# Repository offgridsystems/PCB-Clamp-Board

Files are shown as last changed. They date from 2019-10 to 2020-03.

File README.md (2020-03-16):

# Clamp Board PCBs
### Hardware Files For both Dkblock Clamp Boards - 7.4V and 3.7V (one of each needed for each DKblock)
These are the printed circuit board (PCB) files, CAD files, specification sheets and all technical drawings needed to make each DKblock Clamp board. Note that the bill of materials (BOM) and other technical documents can be opened in [OpenOffice](https://www.openoffice.org) format and PCB files are in [EAGLE](https://www.autodesk.com/products/eagle/overview) format, but they can also be opened and edited in the open source Kicad program.
One version is provided for each board, Rev C are fully tested boards, put into limited production and used on a 72VDC electric scooter named Fido, and a 150VDC VW bug conversion, and other EV projects. 
Also note that the cells have 20 amp fuse protection on each cell. See "Blowup of trace fuse with comments.pdf" graphic

Clamp Board 7.4v 0v OutSide

Clamp Board 7.4v 0v Inside

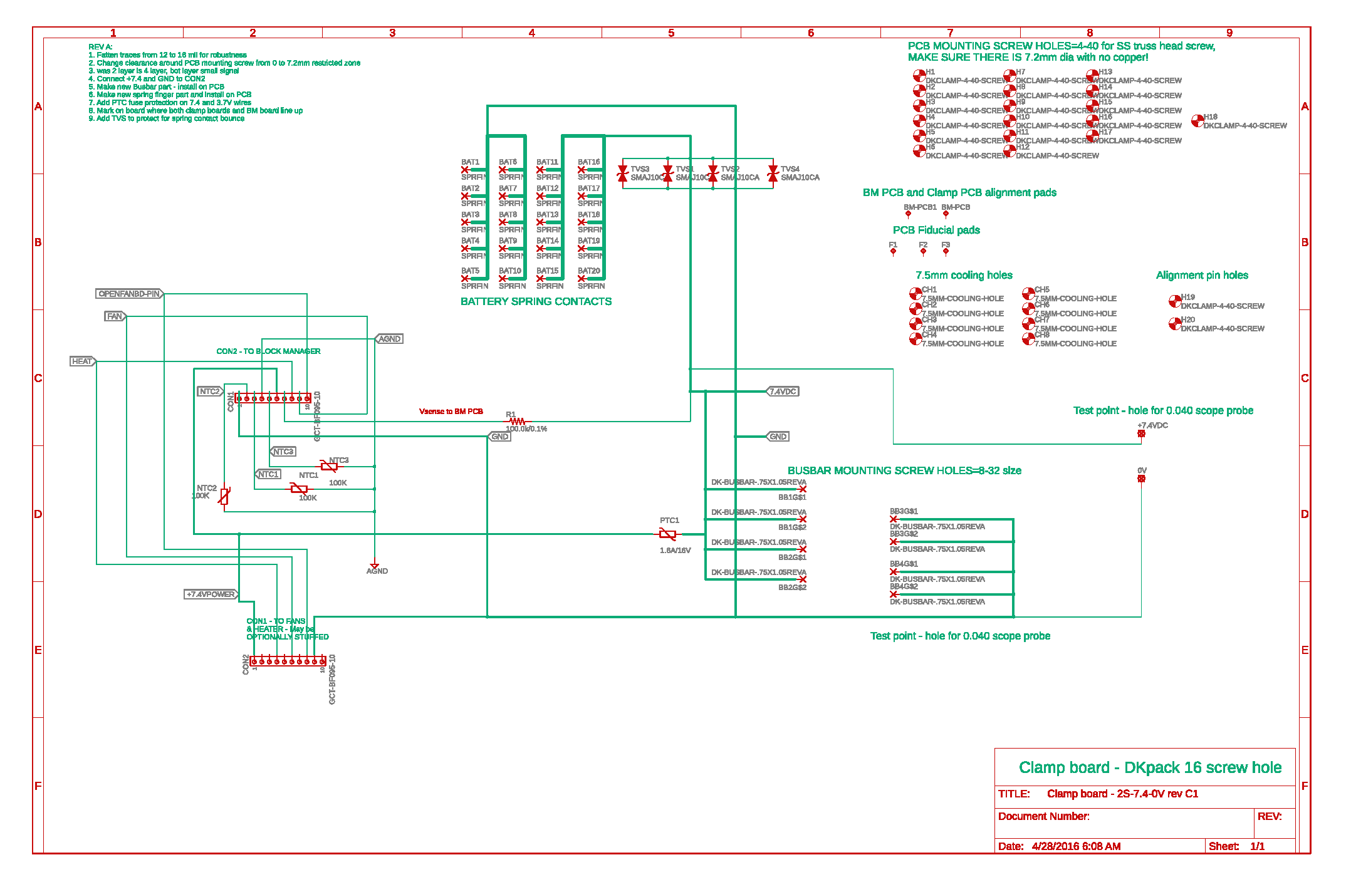
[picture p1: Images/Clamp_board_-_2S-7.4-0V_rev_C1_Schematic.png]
Clamp Board 7.4v 0v Schematic


Clamp Board 3.7v OutSide

Clamp Board 3.7v Inside

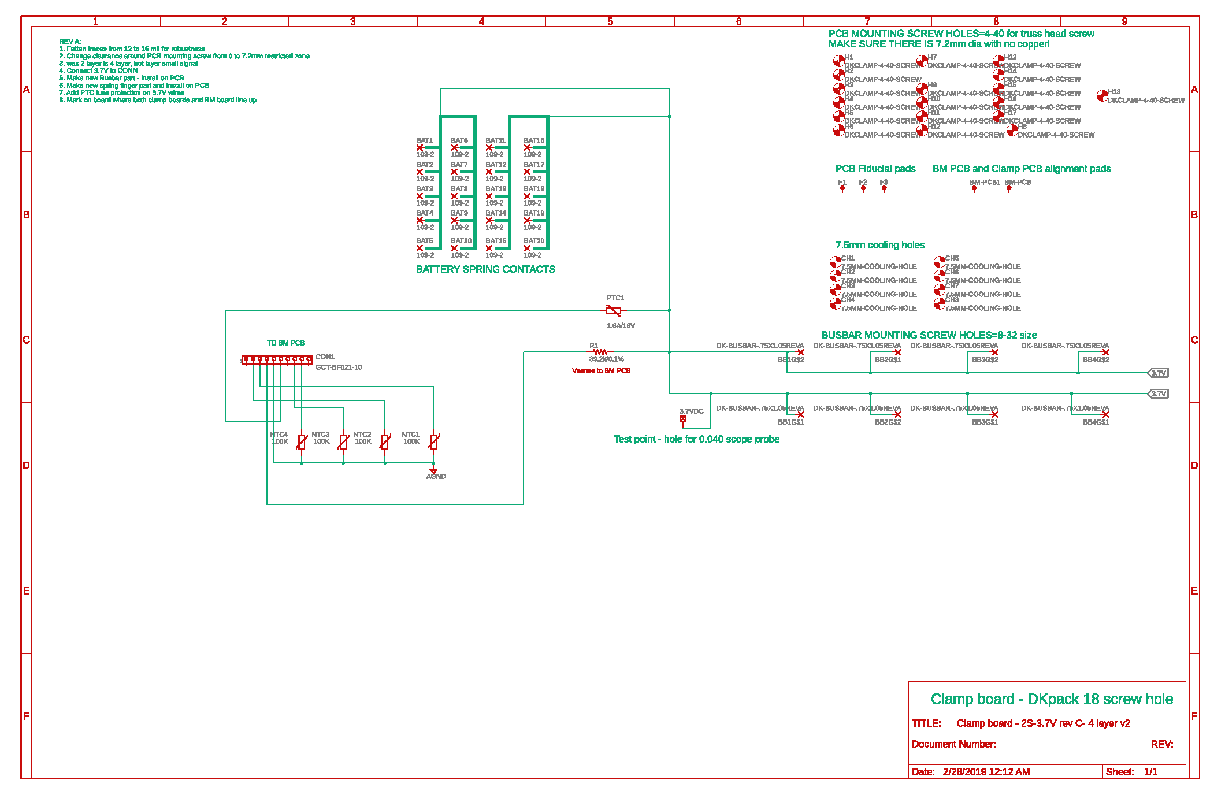
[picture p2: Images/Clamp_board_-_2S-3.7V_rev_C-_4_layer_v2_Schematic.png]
Clamp Board 3.7v Schematic


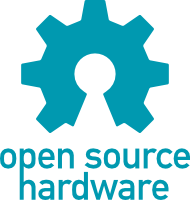
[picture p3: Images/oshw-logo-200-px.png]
Open Hardware


All DKblock software and hardware is released as open source hardware (OSHW) as defined by the OSHWA: https://www.oshwa.org/definition/ and under the JSON license defined at https://www.json.org/license.html

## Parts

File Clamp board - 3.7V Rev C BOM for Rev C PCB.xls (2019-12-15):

BOM – Clamp board 3.7V Rev C For Rev C Boards
Qty | Value | Device | Package | Parts | Description | 1KPRICE | 100PCPRICE | ext 1k | Ext 100 | MPN
1 | 39.2k/0.1% | Resistor SMT | R0603 | R1 | Resistor, SMT | 0.079 | 0.16 | 0.079 |  | Susumu RG1608P-3922-B-T5
4 | 100K | NTC thermistor | R0603 | NTC1, NTC2, NTC3, NTC4 | THERMISTOR NTC 100K OHM 5% 0603 | 0.008 | 0.106 | 0.032 | 0.424 | Murata NCP18WF104J03RB
20 | Gold spring finger | DK springfinger Rev B |  | BAT1-BAT20 | BATTERY CONTACT UNIVERSAL PCB | 0.1 | 0.1 | 2 | 2 | DK spring finger Rev A-1
1 | PCB, FR4 Tg180, 4 layer |  |  | PCB | PCB, 4 layer, 1 ounce copper, TG180 Rev B | 3.43 | 7.7 | 3.43 | 7.7 | Best Tech
1 | 1.6A PTC | PTC fuse | SMT | PTC1 | PTC RESTTBLE 1.60A 16V CHIP 1812 | 0.094 | 0.13 | 0.094 | 0.13 | Bel 0ZCG0160BF2C
1 | 10 pin header | Male single inline pin header | 1 row x 10 positions | CON1 | 2mm single row pin header 10 pin thru hole R/A | 0.6 | 1 | 0.6 | 1 | GCT BF021-10-A-B-0400-0250-N | Sullins NRPN401PARN-RC (40 pin SIP will have to break into 4 pcs of 10 pin connector)
 |  |  |  |  | total |  |  | 6.235 | 11.254

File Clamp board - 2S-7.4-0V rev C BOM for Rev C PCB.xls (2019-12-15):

BOM – Clamp board – 7.4V Rev C BOM for Rev C PCB
Qty | QOH | Ordered | Value | Device | Package | Parts | Description | 1KPRICE | 100PCPRICE | ext 1k | Ext 100 | MPN |  | alternative PN
3 |  | x | 100K/2% | Thermistor NTC | R0603 | NTC1, NTC2, NTC3 | Murata NCP18WF104J03RB | 0.008 | 0.106 | 0.024 | 0.318 | Murata NCP18WF104J03RB
20 |  | x | Gold spring finger | DK springfinger Rev B |  | BAT1, BAT2, BAT3, BAT4, BAT5, BAT6, BAT7, BAT8, BAT9, BAT10, BAT11, BAT12, BAT13, BAT14, BAT15, BAT16, BAT17, BAT18, BAT19, BAT20 | BATTERY CONTACT UNIVERSAL PCB | 0.1 | 0.1 | 2 | 2 | DK spring finger Rev A-1
1 | 50 |  | Female inline socket | 2mm SMT socket, dual entry | TH single row 10 pos | CON1 | 2.0 mm socket, 10 pos, single row, gold, phosphor bronze | 0.27 | 1 | 0.27 | 1 | GCT BF085-10-A-0240-N-D | 3k min | Sullins NPPN101BFCN-RC
1 |  |  | PCB, FR4 Tg180, 4 layer |  |  | PCB | PCB, 4 layer, 1 ounce copper, TG180, Rev B | 3.43 | 7.7 | 3.43 | 7.7 | Best Tech
1 | x |  | 1.6A PTC | PTC fuse | SMT | PTC1 | PTC RESTTBLE 1.60A 16V CHIP 1812 | 0.094 | 0.13 | 0.094 | 0.13 | Bel 0ZCG0160BF2C
4 |  | x | TVS | SMAJ10CA |  | TVS1, TVS2, TVS3, TVS4 | TVS DIODE, Bidirectional 10VWM 21.7VC SMA | 0.08 | 0.105 | 0.32 | 0.42 | ST SMAJ10CA-TR
1 |  | x | 100k/0.1% | Precision resistor | R0603 | R1 | RES SMD 100K OHM 0.1% 1/10W 0603 | 0.079 | 0.16 | 0.079 | 0.16 | Susumu RG1608P-104-B-T5 |  | Yageo RT0603BRD07100KL
 |  |  |  |  |  |  | total |  |  | 6.217 | 11.728
 | DO NOT STUFF THESE PARTS!!! |  |  |  |  | DO NOT STUFF THESE PARTS!!! |  |  |  | 0
1 | 50 |  | Female inline socket | 2mm SMT socket, dual entry | TH single row 10 pos | CON2 | 2.0 mm socket, 10 pos, single row, gold, phosphor bronze | 0.27 | 1 | 0.27 | 1 | GCT BF085-10-A-0240-N-D | 3k min | Sullins NPPN101BFCN-RC

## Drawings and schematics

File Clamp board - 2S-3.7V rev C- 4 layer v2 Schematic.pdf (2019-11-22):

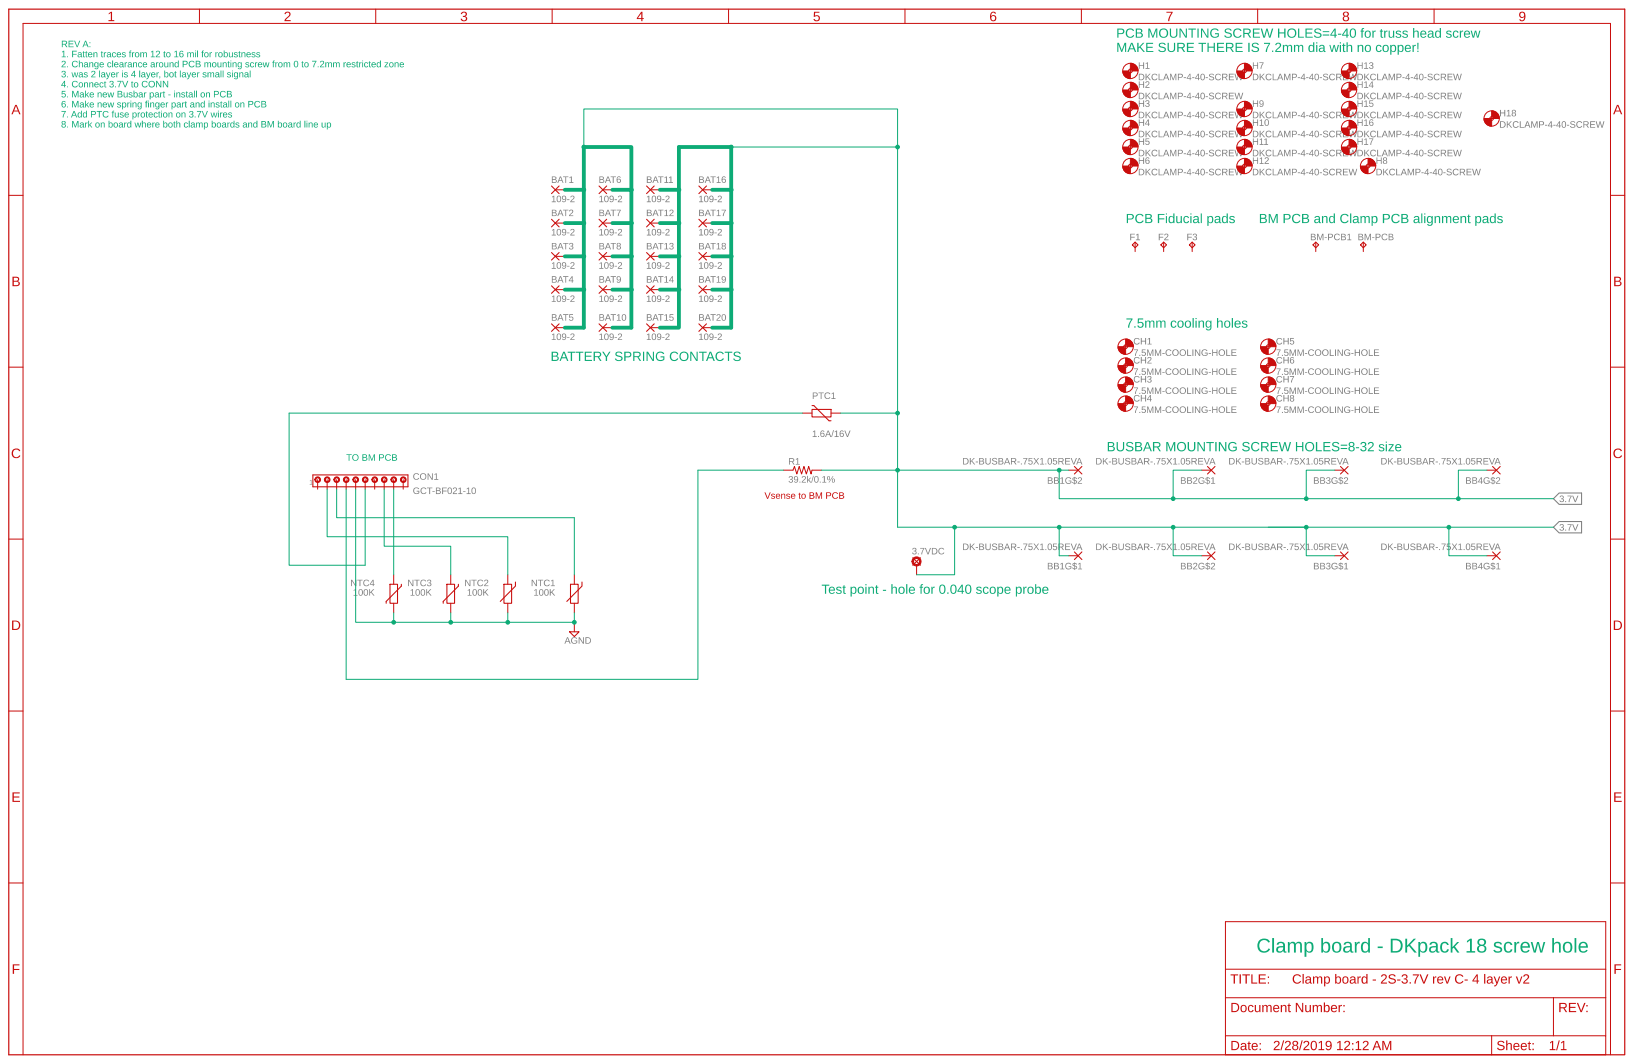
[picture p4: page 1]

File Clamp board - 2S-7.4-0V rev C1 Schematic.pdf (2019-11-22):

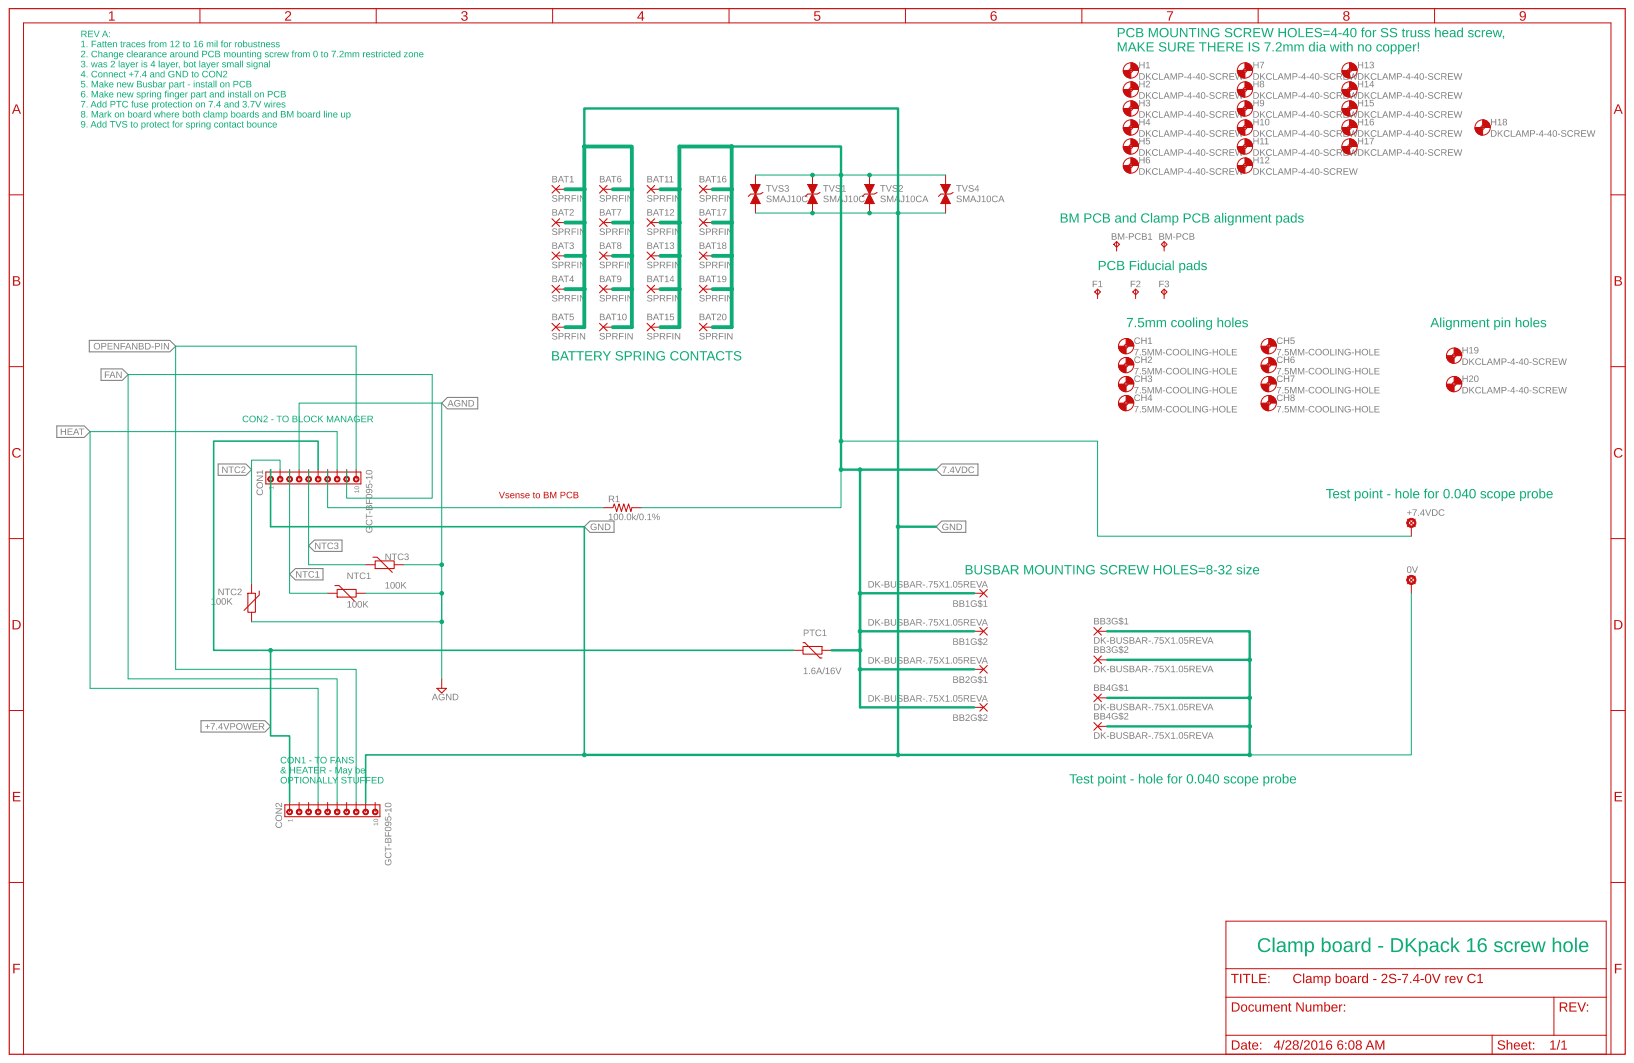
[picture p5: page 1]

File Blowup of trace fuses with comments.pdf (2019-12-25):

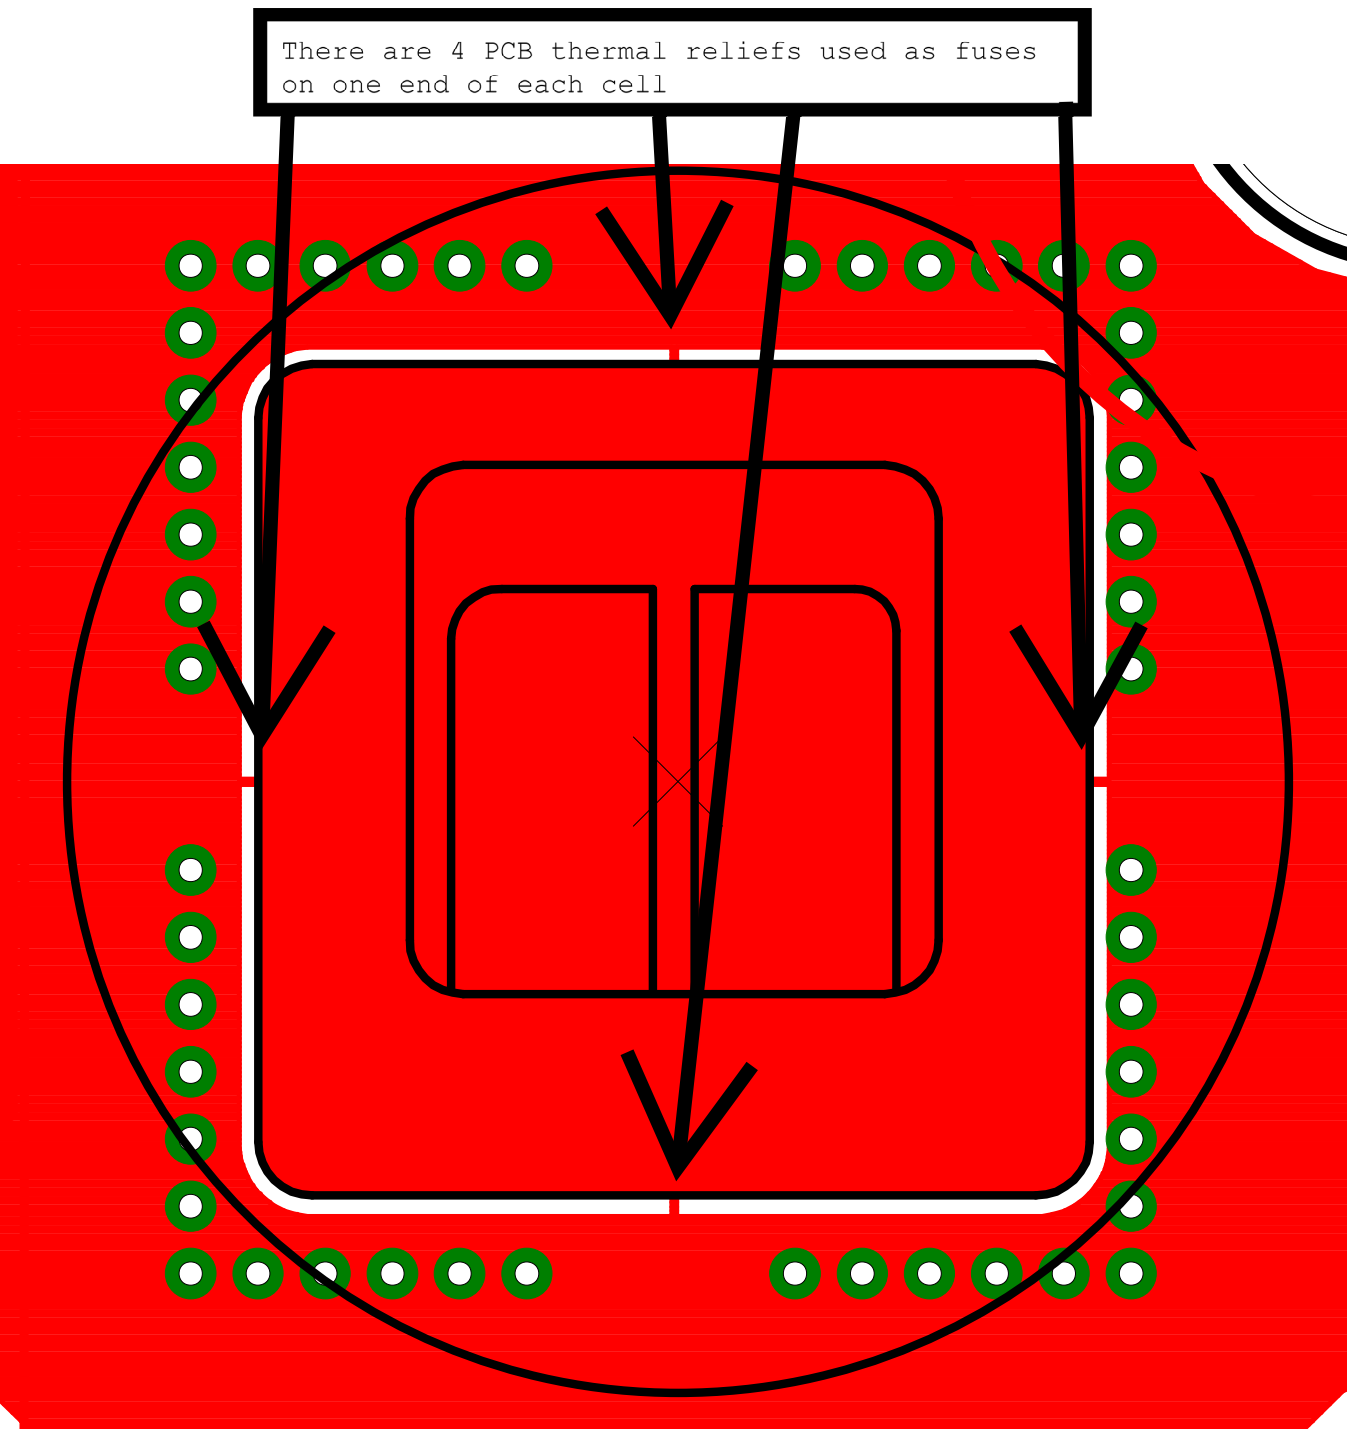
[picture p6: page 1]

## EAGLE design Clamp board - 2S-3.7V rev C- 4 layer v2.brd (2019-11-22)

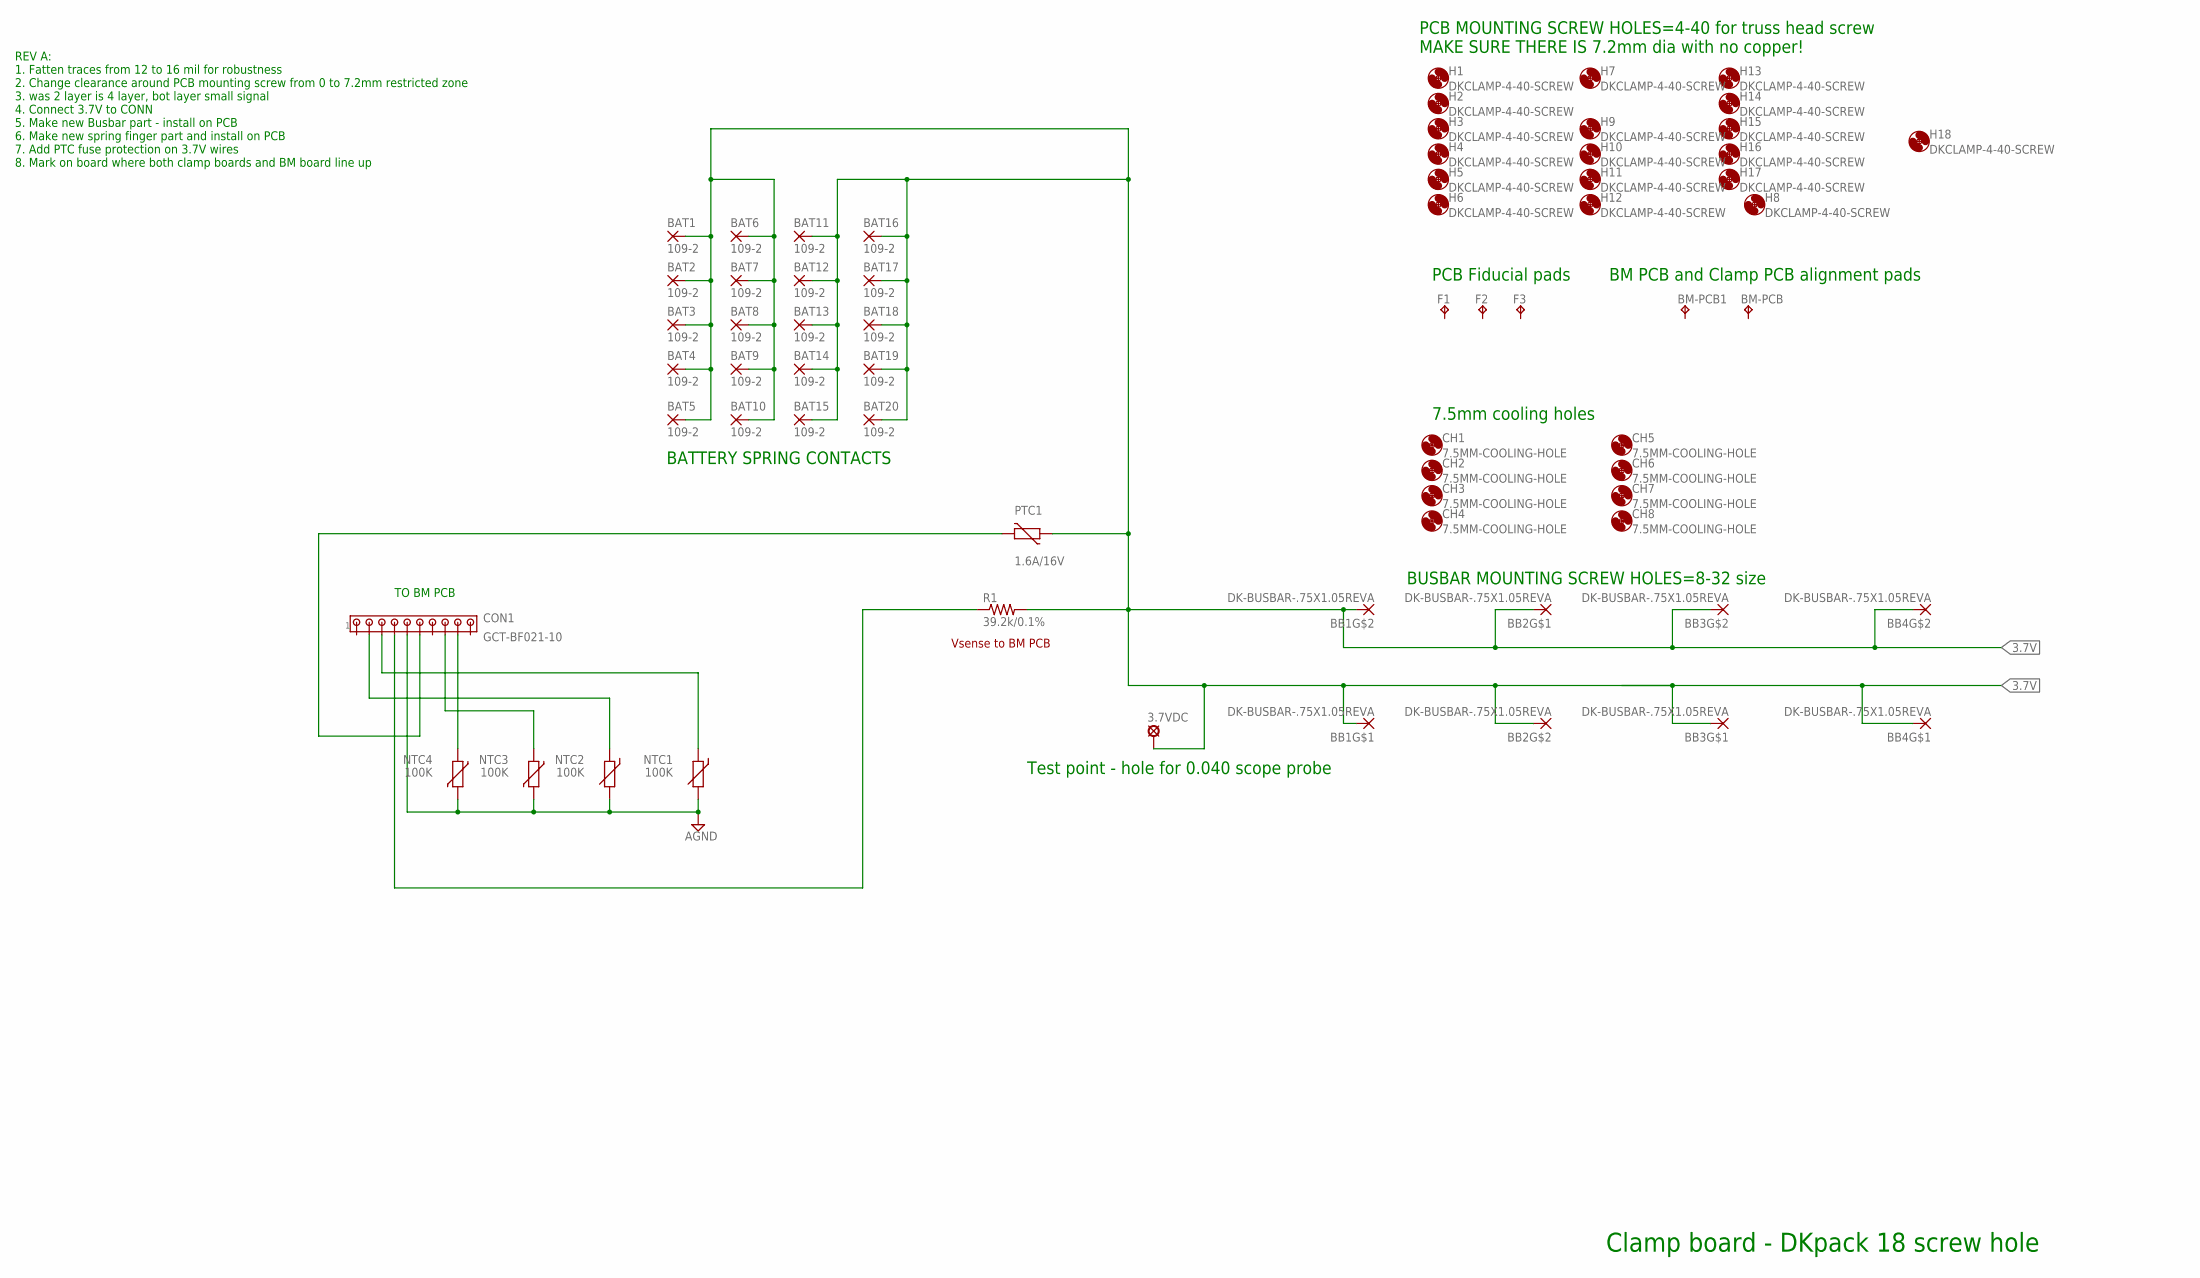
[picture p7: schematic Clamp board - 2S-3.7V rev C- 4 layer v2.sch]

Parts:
3.7VDC: LSP10
BAT1, BAT2, BAT3, BAT4, BAT5, BAT6, BAT7, BAT8, BAT9, BAT10, BAT11, BAT12, BAT13, BAT14, BAT15, BAT16, BAT17, BAT18, BAT19, BAT20: 109-2; DK-SPRING-FINGER-REV2
BB1, BB2, BB3, BB4: DK-BUSBAR-.75X1.05REVA; DKBUSBAR
BM-PCB, BM-PCB1: FIDUCIALTP15SQ; TP15SQ
CH1, CH2, CH3, CH4, CH5, CH6, CH7, CH8: 7.5MM-COOLING-HOLE
CON1: GCT-BF021-10
F1, F2, F3: FIDUCIALB1,27; B1,27
H1, H2, H3, H4, H5, H6, H7, H8, H9, H10, H11, H12, H13, H14, H15, H16, H17, H18: DKCLAMP-4-40-SCREW; 2.95MM-HOLE-FOR-4-40SCREW-DKCLAMP
NTC1, NTC2: 100K; 0603
NTC3, NTC4: 100K; VARISTOR_0603
PTC1: 1.6A/16V; CT/CN1812; MPN Bel 0ZCG0160BF2C
R1: 39.2k/0.1%; R0603

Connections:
3.7V: 3.7VDC.MP, BAT1.2, BAT2.2, BAT3.2, BAT4.2, BAT5.2, BAT6.2, BAT7.2, BAT8.2, BAT9.2, BAT10.2, BAT11.2, BAT12.2, BAT13.2, BAT14.2, BAT15.2, BAT16.2, BAT17.2, BAT18.2, BAT19.2, BAT20.2, BB1.P$2, BB1.P$3, BB2.P$2, BB2.P$3, BB3.P$2, BB3.P$3, BB4.P$2, BB4.P$3, PTC1.1, R1.2
3.7VPOWER: CON1.P$6 (6), PTC1.2
3.7VSCALED: CON1.P$4 (4), R1.1
AGND: CON1.P$5 (5), NTC1.2, NTC2.2, NTC3.2, NTC4.2
NTC1: CON1.P$3 (3), NTC1.1
NTC2: CON1.P$2 (2), NTC2.1
NTC3: CON1.P$8 (8), NTC3.1
NTC4: CON1.P$9 (9), NTC4.1

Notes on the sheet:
Clamp board - DKpack 18 screw hole
PCB MOUNTING SCREW HOLES=4-40 for truss head screw MAKE SURE THERE IS 7.2mm dia with no copper!
BATTERY SPRING CONTACTS
PCB Fiducial pads
7.5mm cooling holes
Test point - hole for 0.040 scope probe
TO BM PCB
BUSBAR MOUNTING SCREW HOLES=8-32 size
Vsense to BM PCB
REV A: 1. Fatten traces from 12 to 16 mil for robustness 2. Change clearance around PCB mounting screw from 0 to 7.2mm restricted zone 3. was 2 layer is 4 layer, bot layer small signal 4. Connect 3.7V to CONN 5. Make new Busbar part - install on PCB 6. Make new spring finger part and install on PCB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
BM PCB and Clamp PCB alignment pads

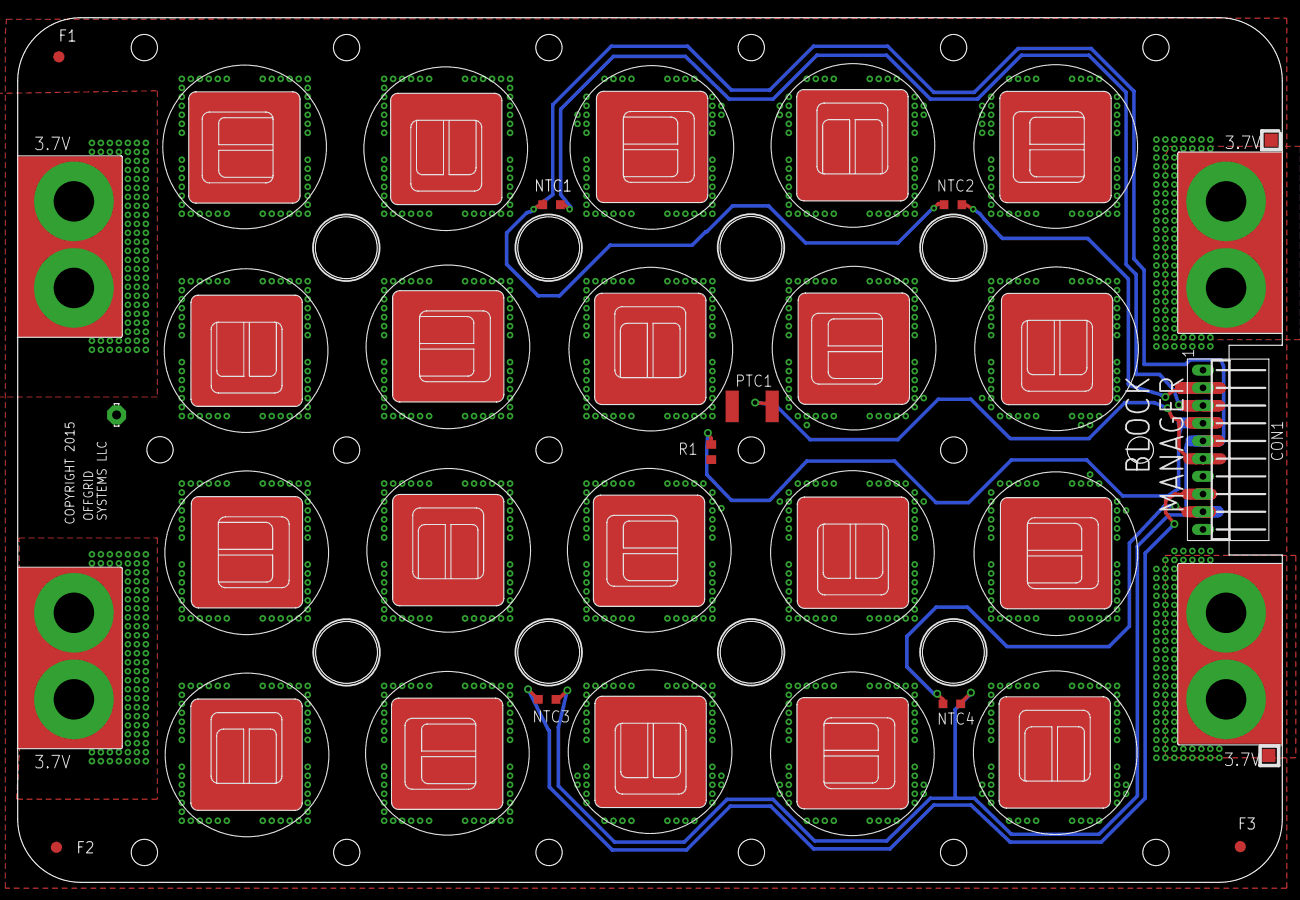
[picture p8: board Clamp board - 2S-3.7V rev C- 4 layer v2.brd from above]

Board: 4 copper layers, 142.9 x 97.7 mm, 63 parts (0 on the bottom side), 8 nets.

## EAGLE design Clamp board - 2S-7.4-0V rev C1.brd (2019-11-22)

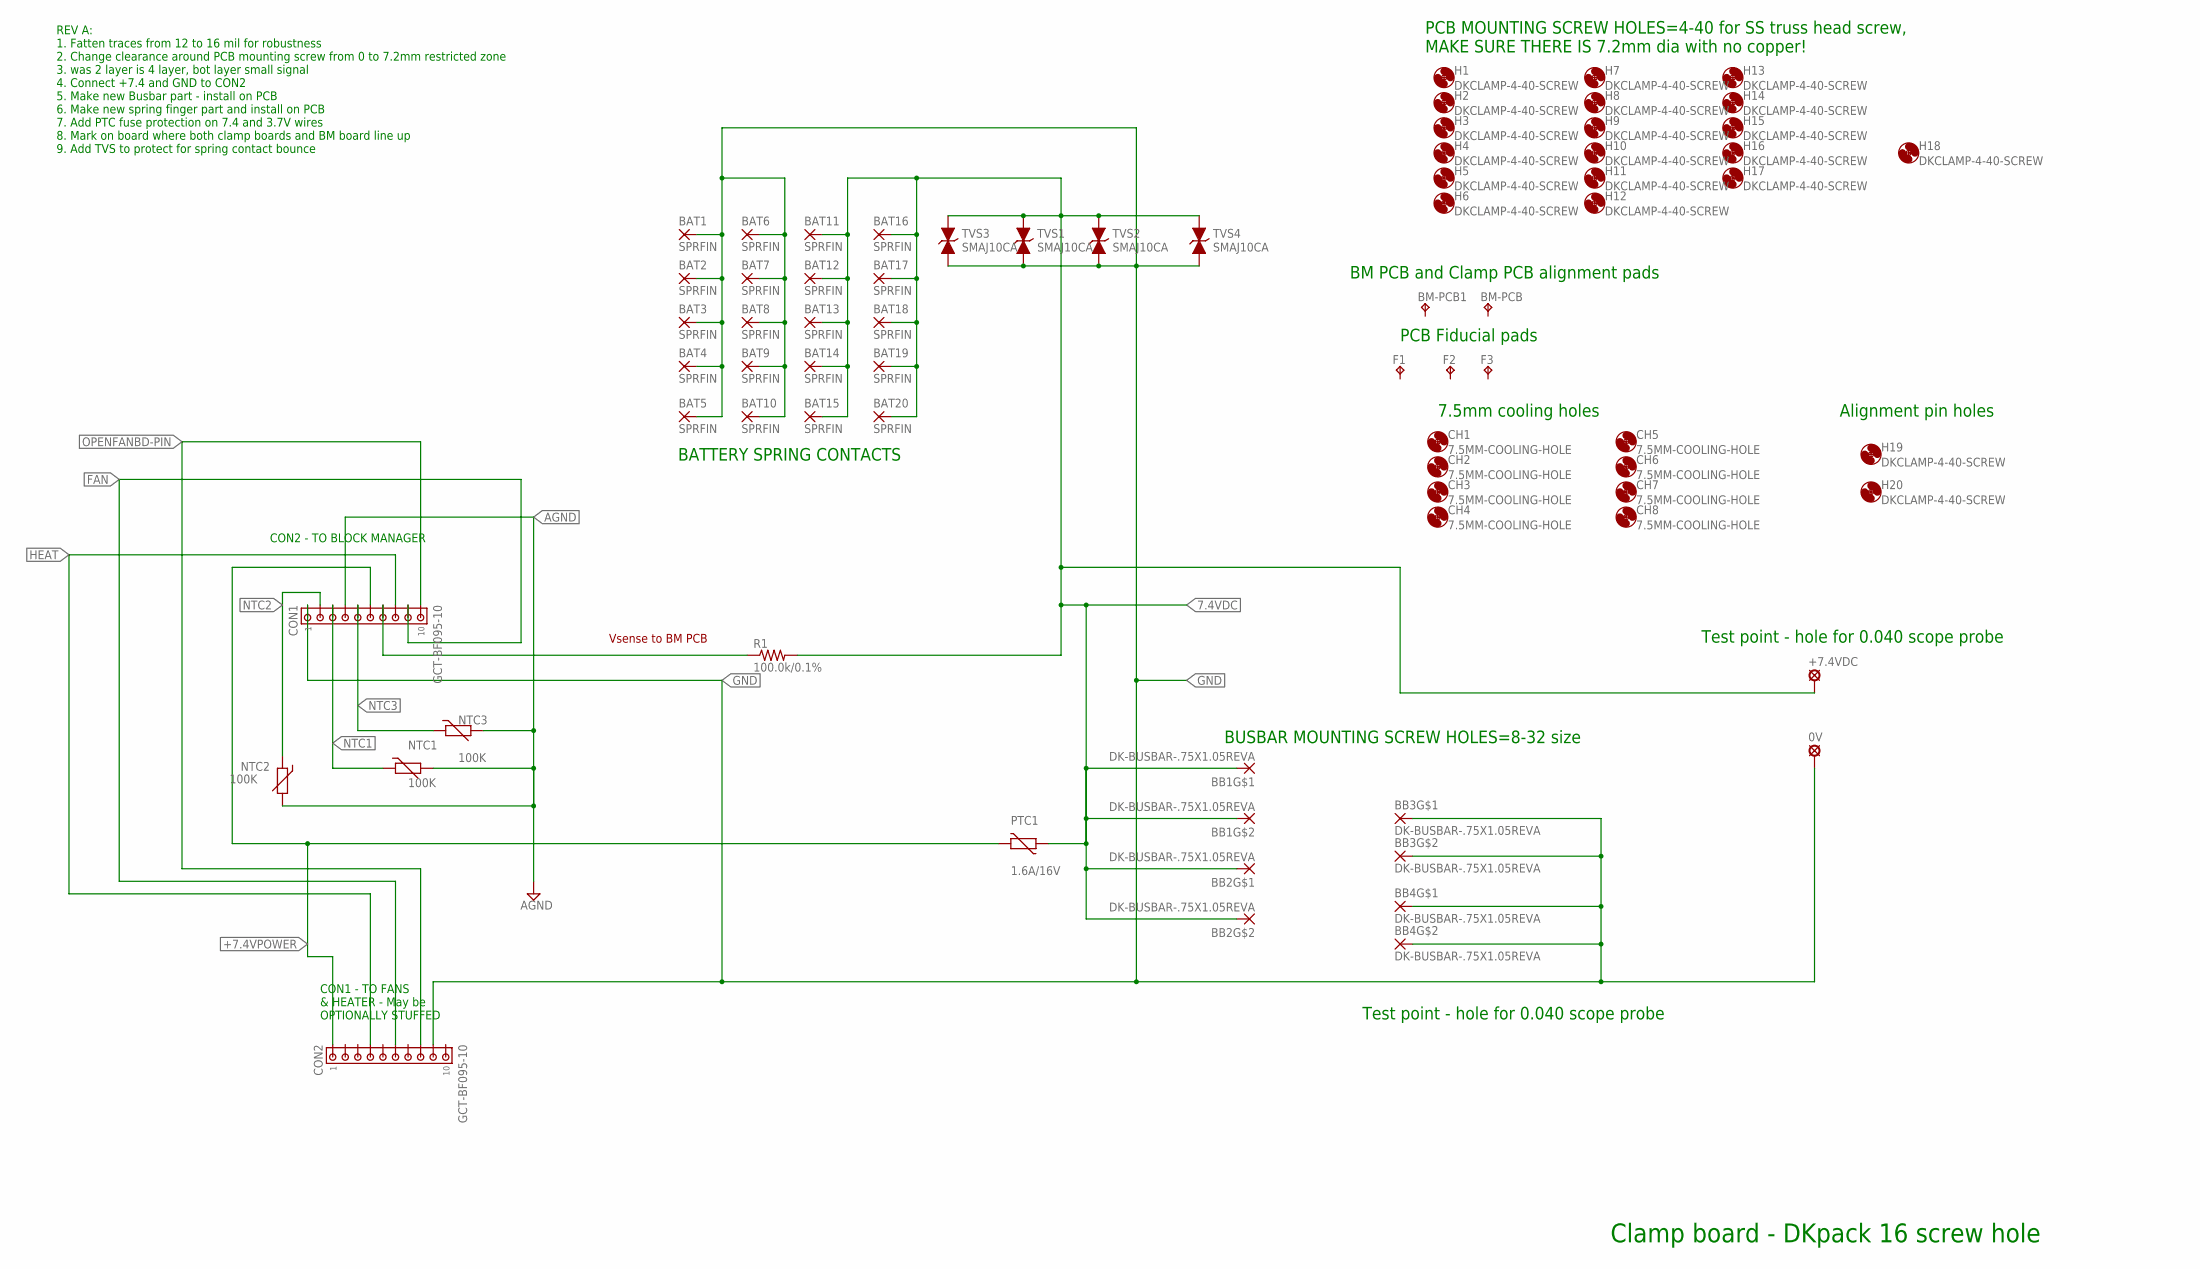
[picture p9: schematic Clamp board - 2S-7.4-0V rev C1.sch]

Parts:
0V: LSP10
+7.4VDC: LSP10
BAT1: SPRFIN; DK-SPRING-FINGER-REV2; MPN Keystone 109-2
BAT2, BAT3, BAT4, BAT5, BAT6, BAT7, BAT8, BAT9, BAT10, BAT11, BAT12, BAT13, BAT14, BAT15, BAT16, BAT17, BAT18, BAT19, BAT20: SPRFIN; DK-SPRING-FINGER-REV2
BB1, BB2, BB3, BB4: DK-BUSBAR-.75X1.05REVA; DKBUSBAR
BM-PCB, BM-PCB1: FIDUCIALTP15SQ; TP15SQ
CH1, CH2, CH3, CH4, CH5, CH6, CH7, CH8: 7.5MM-COOLING-HOLE
CON1, CON2: GCT-BF095-10; GCT-BF085-10
F1, F2, F3: FIDUCIALB1,27; B1,27
H1, H2, H3, H4, H5, H6, H7, H8, H9, H10, H11, H12, H13, H14, H15, H16, H17, H18, H19, H20: DKCLAMP-4-40-SCREW; 2.95MM-HOLE-FOR-4-40SCREW-DKCLAMP
NTC1, NTC2, NTC3: 100K; 0603; MPN MURATA NCP18WF104J03RB
PTC1: 1.6A/16V; CT/CN1812; MPN Bel 0ZCG0160BF2C
R1: 100.0k/0.1%; R0603
TVS1, TVS2, TVS3, TVS4: SMAJ10CA; SMAJ; MPN ST SMAJ10CA-TR

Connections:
7.4VDC: +7.4VDC.MP, BAT11.2, BAT12.2, BAT13.2, BAT14.2, BAT15.2, BAT16.2, BAT17.2, BAT18.2, BAT19.2, BAT20.2, BB1.P$2, BB1.P$3, BB2.P$2, BB2.P$3, PTC1.1, R1.2, TVS1.K (C), TVS2.K (C), TVS3.K (C), TVS4.K (C)
7.4VSCALED: CON1.P$7 (7), R1.1
+7.4VPOWER: CON1.P$6 (6), CON2.P$1 (1), PTC1.2
AGND: CON1.P$4 (4), NTC1.2, NTC2.2, NTC3.2
FAN: CON1.P$9 (9), CON2.P$6 (6)
GND: 0V.MP, BAT1.2, BAT2.2, BAT3.2, BAT4.2, BAT5.2, BAT6.2, BAT7.2, BAT8.2, BAT9.2, BAT10.2, BB3.P$2, BB3.P$3, BB4.P$2, BB4.P$3, CON1.P$1 (1), CON2.P$9 (9), TVS1.A, TVS2.A, TVS3.A, TVS4.A
HEAT: CON1.P$8 (8), CON2.P$4 (4)
NTC1: CON1.P$3 (3), NTC1.1
NTC2: CON1.P$2 (2), NTC2.1
NTC3: CON1.P$5 (5), NTC3.1
OPENFANBD-PIN: CON1.P$10 (10), CON2.P$8 (8)

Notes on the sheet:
Clamp board - DKpack 16 screw hole
PCB MOUNTING SCREW HOLES=4-40 for SS truss head screw, MAKE SURE THERE IS 7.2mm dia with no copper!
BATTERY SPRING CONTACTS
PCB Fiducial pads
7.5mm cooling holes
BUSBAR MOUNTING SCREW HOLES=8-32 size
Test point - hole for 0.040 scope probe
CON1 - TO FANS & HEATER - May be OPTIONALLY STUFFED
CON2 - TO BLOCK MANAGER
REV A: 1. Fatten traces from 12 to 16 mil for robustness 2. Change clearance around PCB mounting screw from 0 to 7.2mm restricted zone 3. was 2 layer is 4 layer, bot layer small signal 4. Connect +7.4 and GND to CON2 5. Make new Busbar part - install on PCB 6. Make new spring finger part and instal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
Vsense to BM PCB
BM PCB and Clamp PCB alignment pads
Alignment pin holes

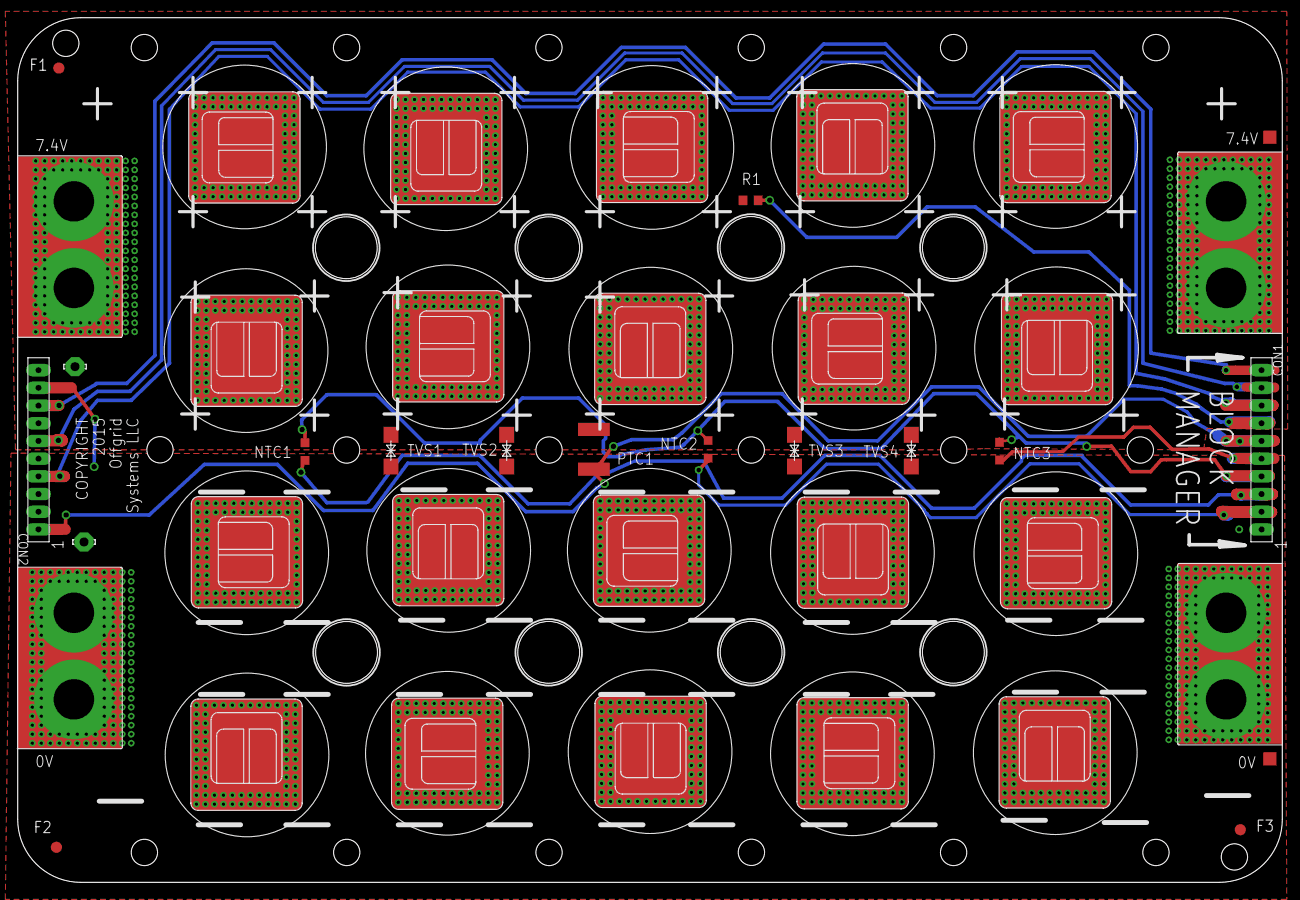
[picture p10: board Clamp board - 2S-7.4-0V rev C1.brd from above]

Board: 4 copper layers, 142.9 x 97.7 mm, 70 parts (0 on the bottom side), 11 nets.

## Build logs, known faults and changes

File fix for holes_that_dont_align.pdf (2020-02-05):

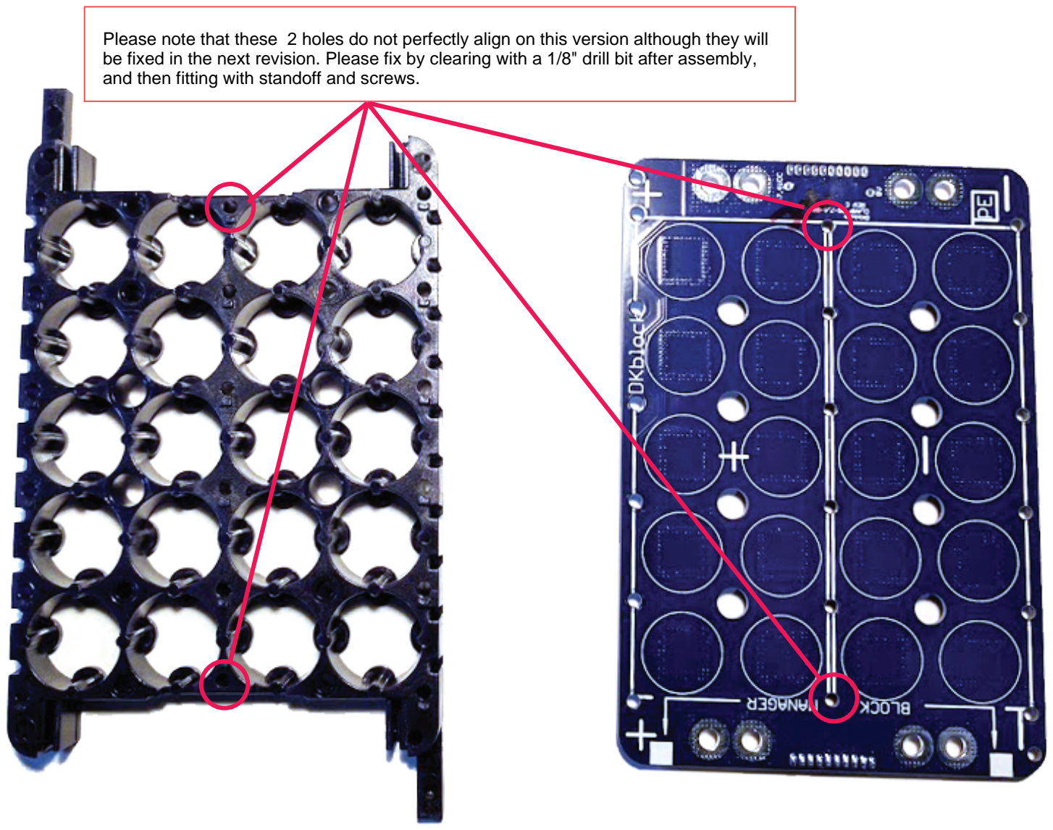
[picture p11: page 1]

Please note that these 2 holes do not perfectly align on this version although they will be fixed in the next revision. Please fix by clearing with a 1/8" drill bit after assembly, and then fitting with standoff and screws.

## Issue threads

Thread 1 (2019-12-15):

MPN for battery spring on clamp board is missing

bvkuik, 2019-12-15:
I'm looking for the MPN of those battery spring contacts :)

offgridsystems, 2019-12-15:
Sorry bvkuik, that is a custom part since I could not find a single spring in the world that worked for DKblock, and believe me I tried very very hard! So I give you the drawings to make that part at https://github.com/offgridsystems/Documents/tree/master/DKblock%20Spring%20contact%20OSHW
and I since I have some stock in the part also, I can put them up on ebay for something near cost of say a lot of 20 for 5 bucks including shipping. Also thank you I did not notice the current Bill of Materials was missing also, so that has been added to the repo. Thank you very much!

Closed 2019-12-29.

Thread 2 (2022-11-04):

How should I submit these plans to JLPCB or PCBway?

MichaelMartinez, 2022-11-04:
Hello!

I really, really love your design and would really like to make a bunch of them. Currently, I am recycling cells from old laptops and using them in all manner of projects. I have 400 or 500 cells to use.

I found your ebay store with springs and cell holders, but I could not find any of the boards. I downloaded the files and submitted to JLPCB and PCBway. They accept the brd and sch files as gerber files. I can load the BOM and to proceed I need a CPL file for drilling. I didn't see one in the repo. So, I tried to put these into KiCAD, but I really don't know what I am doing in that program and was unsuccessful. I am going to try and learn a bit and give it a go.

I built a 3D printer, an ebike (13S10P monster) and CNC machine from kits. I tell you that to let you know I am not afraid to solder, program, make cables/adapters, test and/or make mistakes.

What can I do to have a complete project ready to submit to JLPCB or PCBway for manufacture? I am more than willing to buy parts that are unobtainium from mouser or digikey from you as well. Or attempt to pay you to make a repo that would have these files ready to submit. Thank you from the bottom of my heart for putting this idea out there!

thejobbitt, 2022-11-05:
Hey Michael, we are glad you are interested in the project. Give me a some time to talk to Tim (DK block inventor) and see if he has any stock or if he has a recommended fab house that would do both PCB and pick and place.

All the designs are SMD and I would not recommend hand soldering unless you have the tools to do so.

Please ping again if too much time passes.

offgridsystems, 2022-11-05:
Thanks for coming in Nick, apprecate the help! And I'll for sure give
you full access, thought that was already true.

For Michael, I for sure have clamp boards, if that is what he needs. I'm
in a V2 redesign on the control board (Block Manager) and Pack
Supervisor boards so that is not yet available. The new V2 boards will
work with the old clamp boards, so that will be alright.

I just need to get the store updated with the new boards, give me a few
days ok?!

t

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

MichaelMartinez, 2022-11-05:
> Hey Michael, we are glad you are interested in the project. Give me a some time to talk to Tim (DK block inventor) and see if he has any stock or if he has a recommended fab house that would do both PCB and pick and place.

Great thank you...

> All the designs are SMD and I would not recommend hand soldering unless you have the tools to do so.

Ok, I definitely wouldn't want to hand solder them in that case. PCBWAY and JLPCB have a great service that will make cards at very reasonable prices. It has been my experience that the assembly they provide are top notch given all the files in formats they accept.

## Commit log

2019-11-22 Major Push
    [Clamp board - 2S-3.7V rev C- 4 layer v2.brd, Clamp board - 2S-3.7V rev C- 4 layer v2.sch, Clamp board - 2S-7.4-0V rev C1.brd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]
2020-02-05 Hole alignment fix (until next revision)
2020-03-16 kicad update

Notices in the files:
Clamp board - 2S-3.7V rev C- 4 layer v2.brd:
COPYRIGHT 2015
